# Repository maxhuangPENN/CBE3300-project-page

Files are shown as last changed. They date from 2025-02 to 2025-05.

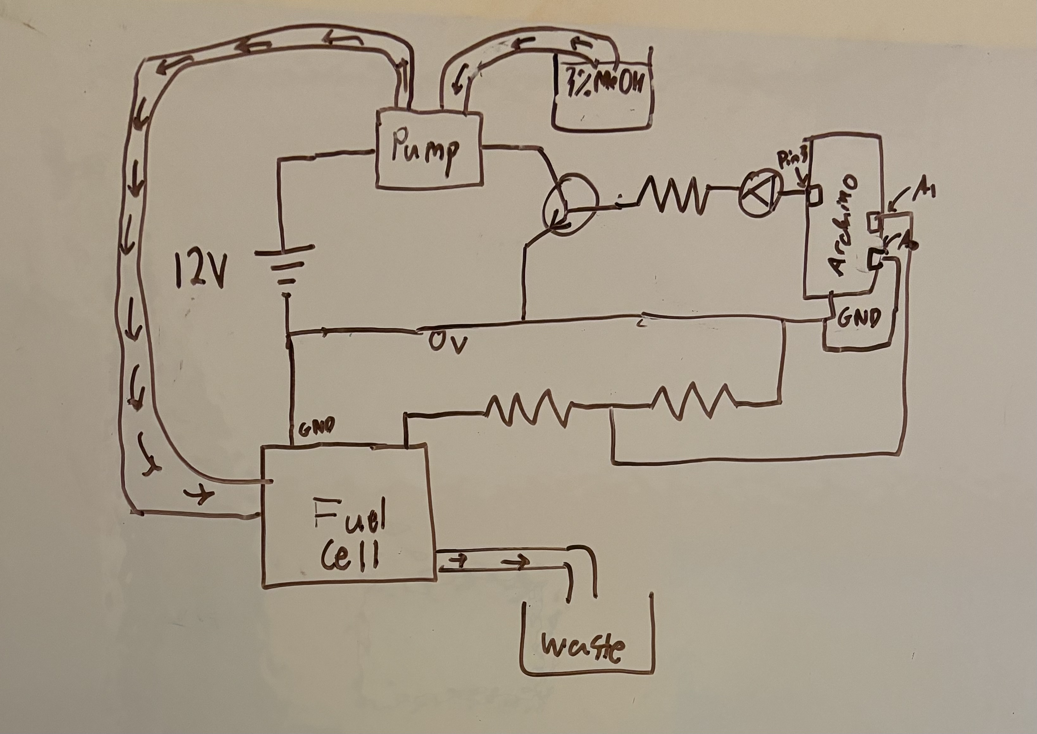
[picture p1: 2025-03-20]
IMG_6256.jpg

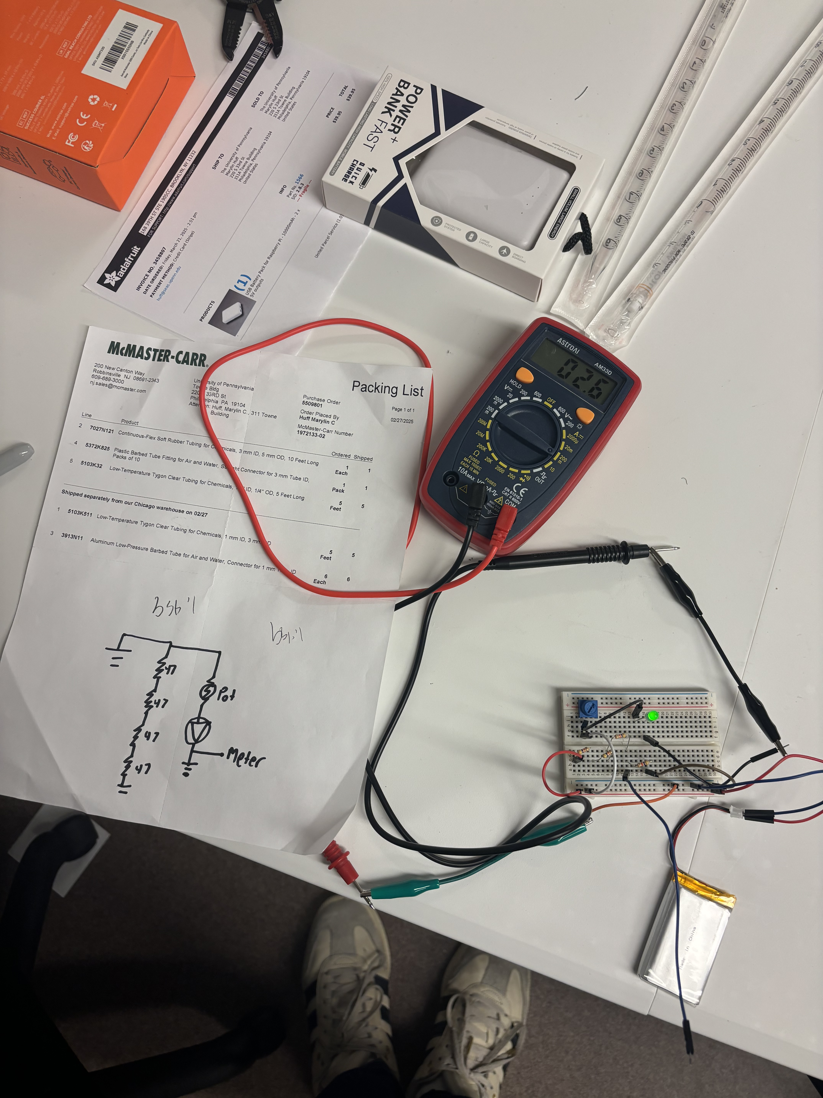
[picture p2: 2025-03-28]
IMG_6270.jpg

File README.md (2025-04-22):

---
title: "Project: Direct Methanol Fuel Cell (DMFC)"
toc: true
toc-depth: 2
numbersections: true
colorlinks: true
abstract-title: Summary
abstract: |
  This project explores the design and prototyping of a Direct Methanol Fuel Cell (DMFC) system using a 10-cell Flex-Stak from the Fuel Cell Store. 
  The cell operates on 3% methanol (~1M), and is designed to output sufficient voltage and current to charge a 20,000 mAh battery pack within 24 hours.
  
  Builders will gain experience with electrochemistry, fuel cell operation, real-time electronics integration with Arduino, and chemical process control. 
  Further extensions include MEA fabrication and advanced catalyst implementation.

  Approximate time: 20–30 person-hours.
---

# DMFC Project – Methanol Dynamics
University of Pennsylvania – CBE 3300B

---

## Project Description

This project explores the design and prototyping of a Direct Methanol Fuel Cell (DMFC) using a 10-cell Flex-Stak. It integrates passive and active fuel delivery, peristaltic pumping, and Arduino-based control logic to modulate methanol flow and monitor system voltage in real time.

Our goal is to develop a system that can charge a 20,000 mAh power bank in less than 24 hours while remaining safe, modular, and efficient. Future goals include fabricating our own MEA and testing alternate catalyst configurations.

---

## Background

DMFC stack and tubing setup

A DMFC converts chemical energy directly into electrical energy via redox reactions. Methanol is oxidized at the anode, producing CO₂, protons, and electrons. The electrons generate current through an external circuit, while protons migrate across a PEM to recombine with oxygen at the cathode, forming water.

**Anode reaction**:  
$$\ce{CH3OH + H2O -> CO2 + 6H+ + 6e-}$$

**Cathode reaction**:  
$$\ce{3/2 O2 + 6H+ + 6e- -> 3H2O}$$

**Overall reaction**:  
$$\ce{CH3OH + 3/2 O2 -> CO2 + 2H2O}$$

The theoretical cell voltage is ~1.20 V per cell, but practical values range between 0.3–0.6 V due to internal losses and crossover.

---

## Project Goals

- Develop a minimum viable DMFC prototype
- Integrate peristaltic pump control via PWM (Arduino)
- Monitor live voltage and adjust flow dynamically
- Run extended tests to estimate methanol consumption and power output
- Optimize stack layout and fuel delivery (horizontal vs vertical, vapor vs liquid)
- Charge a 20,000 mAh power bank in < 24 hours

---

## Equipment & Materials

### Hardware

- 10-cell Flex-Stak DMFC (Fuel Cell Store)
- Arduino Uno
- Diode-protected transistor circuit (2N2222 BJT)
- Peristaltic pump
- 3% methanol solution (~1M)
- Tubing, check valves
- USB data logging via Processing

### Software

- Arduino IDE for control logic and PWM duty modulation
- Processing for real-time plotting and CSV saving of voltage
- Python (optional) for data post-processing

---

## Build Instructions

1. **Assemble fuel cell stack** and torque bolts to 8–10 in-lbs
2. **Hydrate membrane** with distilled water before first use
3. Prepare **3% MeOH in water solution (~1M)** and prime pump lines
4. Upload [Arduino script](#arduino-code) and connect PWM to base of 2N2222 transistor
5. Open [Processing visualization](#processing-code) to log voltage and plot in real time
6. Begin testing and incrementally increase duty cycle or MeOH concentration if needed

---

## Arduino Code

```cpp
int pwmPin = 3; // Digital output pin connected to BJT base
int analogPin = A0; // Reads voltage (resistor divider used)

float dutyCycle = 1;      
float targetFlowrate = 100;
int pwmPeriodMs = 10;

boolean feedback = false;
float targetCellVoltage = 4;
int timer = 0;

void setup() {
  Serial.begin(9600);
  dutyCycle = targetFlowrate / 142.0;
  if (dutyCycle > 1.0) dutyCycle = 1.0;
  pinMode(pwmPin, OUTPUT);
  pinMode(analogPin, INPUT);
}

void loop() {
  int onTime = pwmPeriodMs * dutyCycle;
  int offTime = pwmPeriodMs - onTime;

  int sensorValue = analogRead(analogPin);
  float voltage = 4 * sensorValue * (5.0 / 1023.0);
  Serial.println(voltage);

  digitalWrite(pwmPin, HIGH);
  delay(onTime);
  digitalWrite(pwmPin, LOW);
  delay(offTime);

  if (feedback && timer % 1000 == 0) {
    if (voltage > targetCellVoltage + 0.1) dutyCycle -= 0.01;
    else if (voltage < targetCellVoltage - 0.1) dutyCycle += 0.01;
  }
  timer += pwmPeriodMs;
}

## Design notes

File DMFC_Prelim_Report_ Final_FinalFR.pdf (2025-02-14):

# Preliminary Design Report: Direct Methanol Fuel Cell

### Methanol Dynamics & Company LLP (Max, Jack, Karam)

### February 13, 2025

## Contents

1 Introduction | 2
2 Electrochemical Operation of a Direct Methanol Fuel Cell (DMFC) | 2
3 Prototyping Approach | 4
4 Project Timeline | 6
5 Preliminary Calculations | 8
6 Purchasing List | 10
7 References | 13

## 1 Introduction

This document presents the preliminary design report for our Direct Methanol Fuel Cell (DMFC) prototype. It includes an outline of the physical and chemical principles, relevant calculations, and a detailed prototyping approach.

## 2 Electrochemical Operation of a Direct Methanol Fuel Cell (DMFC)

The direct methanol fuel cell (DMFC) is an electrochemical device that converts the chemical energy of methanol into electrical energy through redox reactions. Unlike combustion, which releases energy primarily as heat, the DMFC harnesses this energy to drive electron flow, producing electricity in a controlled manner.

### 2.1 Anode Reaction: Methanol Oxidation

At the anode, methanol (CH3OH) and water (H2O) undergo oxidation in the presence of a catalyst, typically platinum (Pt) or platinum-ruthenium (Pt-Ru). This reaction results in the formation of carbon dioxide (CO2), protons (H⁺
), and electrons (e⁻):

CH3OH + H2O → CO2 + 6H⁺ + 6e

−

The oxidation pathway can vary, with some intermediates such as formaldehyde (CH2O) and formic acid (HCOOH). However, carbon monoxide (CO) can also form as a byproduct, which can poison the catalyst and reduce efficiency. The incorporation of ruthenium (Ru) helps mitigate this effect by facilitating CO oxidation.

### 2.2 Proton Exchange and Electron Flow

Adjacent to the anode is a proton exchange membrane (PEM), often made of Nafion, which plays a crucial role in directing charge flow. This membrane allows the passage of protons (H⁺
) from the anode to the cathode while preventing unwanted methanol crossover, a major source of efficiency loss in DMFCs. Meanwhile, the electrons generated at the anode travel through an external circuit, creating an electric current before reaching the cathode.

### 2.3 Cathode Reaction: Oxygen Reduction

At the cathode, oxygen gas (O2) is reduced in the presence of platinum or specialized catalysts such as RuSe, which help mitigate performance losses due to methanol crossover. The incoming oxygen reacts with protons from the membrane and electrons from the external circuit to form water:

3
2

O2 + 6H

+ + 6e

− → 3H2O

This reaction completes the circuit, sustaining continuous electron flow and thus electrical power generation.

### 2.4 Theoretical Maximum Voltage and Energy Efficiency

The ideal electromotive force (EMF) of a DMFC, derived from the Gibbs free energy change of the overall reaction:

3
2

O2 + CH3OH → CO2 + 2H2O

is approximately 1.2V per cell. However, due to losses from activation polarization, ohmic resistance, and mass transport limitations, practical operating voltages typically range between 0.3V and 0.6V per cell.
The overall efficiency of a DMFC is limited by factors such as methanol crossover, catalyst degradation, and water management. The Nernst equation can be used to account for real operating conditions and concentration variations:

E = E

0 −

RT
nF

ln Q

where: - E

0 = 1.20V (standard cell voltage), - R is the universal gas constant, - T is the operating temperature, - n = 6 (number of electrons transferred), - F is the Faraday constant, - Q represents the reaction quotient.

### 2.5 Summary of the DMFC Operation

- Anode: Methanol and water oxidize, producing protons, electrons, and carbon dioxide.
- Proton Exchange Membrane: Conducts protons to the cathode while preventing direct methanol crossover.
- Electron Flow: Electrons travel through an external circuit, generating electrical power.
- Cathode: Oxygen is reduced, combining with protons and electrons to form water.
- Voltage Output: The theoretical voltage is 1.2V, but actual efficiency and power output depend on operating conditions.

By optimizing reaction kinetics, catalyst selection, and fuel delivery methods, the performance of DMFCs can be significantly enhanced for real-world applications.

## 3 Prototyping Approach

Our prototyping approach follows a staged methodology aimed at optimizing the design and achieving the highest possible voltage for our direct methanol fuel cell (DMFC).

### 3.1 Minimum Viable Prototype (MVP)

Our first goal is to construct a functional minimum viable prototype (MVP) using a liquid methanol feed with passive control. This design choice ensures simplicity and feasibility in the early stages while providing a solid baseline for future modifications.

- Membrane Electrode Assembly (MEA): Instead of fabricating our own initially, we will purchase a commercial MEA, ensuring reliability and allowing us to quickly test basic system functionality.
- Passive Fuel Delivery: Passive DMFCs operate without auxiliary equipment such as pumps or sensors, relying on diffusion and natural convection to transport reactants (methanol and oxygen). This simplifies the initial build and reduces complexity.
- Basic Performance Metrics: We will measure voltage and current output to assess the baseline performance before proceeding with optimizations.

### 3.2 Optimization and Enhancements

Once the MVP is operational, we will explore modifications to improve performance, focusing on increasing voltage output. Our planned optimizations include:

### 3.2.1 Active Control Implementation

- Introducing sensors (e.g., flow meters, temperature sensors, and concentration monitors) to monitor and control reactant flow dynamically.
- Using Arduino-based control systems to regulate fuel flow rate and oxygen supply.
- Implementing an external fuel delivery system, such as a micropump, for better methanol concentration control.

### 3.2.2 Vapor vs. Liquid Feed Comparison

- Testing vaporized methanol feed instead of a direct liquid feed. Vapor feed reduces methanol crossover, increases reaction rates, and can improve fuel cell efficiency.
- Assessing temperature effects on reaction kinetics, as vapor feed operates at higher temperatures, potentially improving performance.

### 3.2.3 Geometrical Configurations

- Evaluating horizontal vs. vertical orientations for the fuel cell stack to optimize carbon dioxide removal and fuel distribution.
- Investigating different anode diffusion layers (ADL) and cathode diffusion layers (CDL) to improve fuel transport and reaction efficiency.

### 3.2.4 MEA Fabrication

- Concurrently, we will attempt to build our own MEA from individual components, including a proton exchange membrane (PEM) and Pt-Ru catalyst layers.
- If the self-assembled MEA does not meet performance expectations, we will continue to rely on the purchased MEA while refining our fabrication techniques.

### 3.2.5 Final Voltage Benchmark and System Refinement

- Our target voltage is 5V, requiring serial or parallel stacking of multiple fuel cells.
- We will fine-tune parameters such as methanol concentration, flow rates, and operating temperature to maximize efficiency.

### 3.3 Future Considerations

Once the fundamental optimizations are completed, we will explore further advanced techniques, such as:

- Alternative catalysts to reduce reliance on platinum.
- 3D printing of structural components to streamline manufacturing.
- Hybrid fuel systems, integrating hydrogen or other fuels for improved energy density.

This structured prototyping approach ensures a logical progression from a functional baseline to an optimized DMFC capable of achieving high voltage and efficiency.

## 4 Project Timeline

The following timeline outlines the key milestones and deliverables for our Direct Methanol Fuel Cell (DMFC) development. Our final presentation is scheduled for Week 14, and we will use the time leading up to it to iteratively refine our design, optimize performance, and validate results.

### 4.1 Development Plan

- Week 2 (Completed): Literature review, background research on DMFC operation, and identification of required materials.
- Week 4 (Current Week):

– Karam emails Dr. Huff to confirm parts order.

– Initiate 3D printing of preliminary components.

– Complete and submit preliminary design report by Friday, February 7.

- Week 5:

– Finalize component orders and track deliveries.

– Begin assembling the initial prototype with purchased MEA.

– Conduct preliminary voltage tests to establish baseline performance.

- Weeks 6-7:

– Integrate sensors and begin active control implementation.

– Evaluate liquid feed performance and compare to theoretical predictions.

– Troubleshoot any early-stage performance issues.

- Week 8:

– Assess horizontal vs. vertical fuel cell orientation for optimal CO2 removal.

– Test impact of varying methanol concentrations on performance.

– Refine 3D-printed components if necessary.

- Weeks 9-10:

– Investigate vapor feed vs. liquid feed system performance.

– Implement Arduino-based active control for flow rate optimization.

– Verify sensor accuracy and calibrate data collection systems.

- Week 11:

– Attempt self-assembly of MEA using PEM and catalyst layers.

– Compare performance of self-made MEA against the commercial MEA.

– Identify any efficiency losses and determine feasibility of custom MEA.

- Weeks 12-13:

– Conduct final optimization rounds to maximize voltage output.

– Implement fine-tuned methanol and oxygen flow controls.

– Finalize system architecture to reach 5V target.

- Week 14 (Final Presentation Week):

– Deliver final presentation showcasing experimental results, optimizations, and key takeaways.

– Submit final report with performance benchmarks and analysis.

## 5 Preliminary Calculations

Accurate theoretical calculations are essential for predicting the performance of our direct methanol fuel cell (DMFC) and optimizing its efficiency.

### 5.1 Nernst Equation Calculations

The voltage output of a DMFC can be estimated using the Nernst equation, which accounts for concentration effects:

E = E0 −

RT
nF

ln Q

where:

- E0 = 1.20 V (Standard electromotive force for DMFC) [1]
- R = 8.314 J/(mol·K) (Universal gas constant)
- T = 298 K (Assumed room temperature)
- n = 6 (Number of electrons transferred per reaction)
- F = 96, 485 C/mol (Faraday’s constant)
- Q is the reaction quotient, given by:

Q =

[CO2][H2O]²
[CH3OH][O2]

3/2

Input Parameters:

- Methanol concentration: Typically ranges from **0.1 M to 1.0 M** in DMFCs.
- Oxygen partial pressure: **0.21 atm** (assuming air as the oxidant).
- Carbon dioxide concentration: Starts near **0 atm**, depending on reaction rate.
- Estimated reaction quotient: Q ≈ 1 − 10, depending on real conditions.

### 5.2 Theoretical Maximum Voltage

The standard theoretical maximum voltage of a DMFC is:

E0 = 1.20 V

This value represents the ideal potential assuming no losses in the system.

### 5.3 Estimated Efficiency and Target Voltage

Fuel cell efficiency can be estimated from experimental data:

- Assumed efficiency: **40
- Expected operational voltage range: **0.3V - 0.6V per cell**.
- Target voltage for system design: **4V - 6V** by stacking multiple cells.

The system voltage goal of **5V** will be achieved through a combination of optimized methanol feed, temperature control, and serial/parallel stacking.

## 6 Purchasing List

The following is a comprehensive list of components required for constructing and optimizing our direct methanol fuel cell (DMFC) prototype. This includes essential materials, sensors for active control, vapor feed components, and equipment for building our own MEA.

** Clicking on the reference number leads to the References, where we documented all links to purchasing websites.

### 6.1 Core Fuel Cell Components

- Membrane Electrode Assembly (MEA)

– Membrane Thickness: 170 micrometers
– Anode Catalyst: Platinum-Ruthenium (4.0 mg/cm² )
– Cathode Catalyst: Platinum Black (4.0 mg/cm²
)
– Gas Diffusion Layer: Carbon Cloth with Microporous Layer (MPL) – Cost: Starting from $170.00 (2.2 cm x 2.2 cm option) [3]
- Current Collectors

– Material: Gold-plated stainless steel or similar conductive materials – Purpose: Facilitates electron collection and improves electrical contact – Cost: Approximately $30 each [4]

- Proton Exchange Membrane (PEM)

– Material: Nafion (included in MEA)

– Purpose: Allows proton conduction while blocking electrons – Key Consideration: Minimizing methanol crossover

### 6.2 Active Control and Monitoring Components

- Sensors and Meters

– Flow Meters – For measuring methanol and oxygen flow rates
– Temperature Sensors – To monitor heat buildup and optimize reaction conditions
– Concentration Monitors – To ensure proper methanol-to-water ratio
– Voltage and Current Sensors – For real-time electrical performance monitoring
- Control Systems

– Arduino-based Microcontroller – For automated fuel and oxygen flow regulation
– Actuators and Pumps – To enable precise control of methanol feed
– Power Management Module – To integrate the fuel cell with external loads

### 6.3 Vapor Feed System

- Methanol Vaporizer – Converts liquid methanol into gas phase for testing vapor feed performance
- Gas Flow Regulators – To control methanol vapor concentration and delivery rate
- Humidifier Chamber – Ensures proper humidification for proton exchange membrane operation

### 6.4 MEA Fabrication Equipment

- Catalyst Ink Materials – Platinum-ruthenium nanoparticles, solvents, and binders
- Screen Printing Equipment – For catalyst layer deposition on gas diffusion electrodes
- Hot Press – For assembling homemade MEA layers under controlled pressure and temperature
- Electrochemical Workstation – For characterizing custom MEA performance

### 6.5 3D-Printed and Custom Components

- Custom Flow Field Plates – Designed to optimize reactant distribution
- Housing and Fixtures – For secure and leak-proof fuel cell assembly
- Tubing and Connectors – To manage liquid and vapor fuel delivery

This purchasing list ensures that we have all necessary components for our staged prototyping approach, from initial passive control to advanced active regulation and MEA fabrication.

Important to keep in mind:

Items listed that pertain to optimizing our fuel cell beyond the MVP do not have purchasing costs or links associated with them. This is because, once we achieve the MVP, significant testing and experimentation will be required before committing to specific sensors and the type of feed system we want to pursue. For instance, it would be impractical to purchase a vaporizer if we ultimately decide that a liquid feed system is more efficient for our setup.

Additionally, given methanol’s Safety Data Sheet (SDS) considerations, we must carefully evaluate the best methods for delivering vaporized methanol. Our current best approach (recommended by Dr. Huff) involves bubbling nitrogen through methanol to pick up vapor and transport it into the system, but this method is still under evaluation.

Furthermore, we anticipate that many of the basic sensors and equipment required for testing can be sourced from Towne, either through direct access to shared lab resources or by consulting Dr. Huff. While we recognize that borrowing equipment from research labs is not ideal, we believe that simple components like flow meters and temperature sensors should be readily available for our early testing phases.

Finally, once our testing is complete and we finalize our fuel cell’s optimization needs, we do not expect a significant lead time for ordering the required products and sensors, allowing us to proceed efficiently without unnecessary upfront purchases.

## 7 References

## References

[1] Direct Methanol Fuel Cells – Nernst Equation and Performance Analy-
sis. | Available | at: | https://www.sciencedirect.com/topics/chemistry/
direct-methanol-fuel-cell (https://www.sciencedirect.com/topics/chemistry/direct-methanol-fuel-cell)
[2] DMFC Efficiency Study: “The potential efficiency (εf ) of a DMFC for an operational cell e.m.f. (E) of 0.5 V is about 40%.” Available at: https://www.sciencedirect.com/topics/chemistry/direct-methanol-fuel-cell (https://www.sciencedirect.com/topics/chemistry/direct-methanol-fuel-cell)
[3] Fuel Cell Store – Direct Methanol MEA. Available at: https://www.fuelcellstore.com/direct-methanol-mea (https://www.fuelcellstore.com/direct-methanol-mea)
[4] MSE Supplies – Gold-Plated Current Collectors. Available at: https://www.msesupplies.com/products/pt-and-au-wire-0-6-mm-dia-10-mm-length-unit
[5] Methanol-Resistant Oxygen-Reduction Catalysts for Direct Methanol Fuel Cells. Available at: https://www.annualreviews.org/content/journals/10.1146/annurev.matsci.33.072302.093511 (https://www.annualreviews.org/content/journals/10.1146/annurev.matsci.33.072302.093511)
[6] Limiting Current Behavior of the Direct Methanol Fuel Cell. Available at: https: //www.sciencedirect.com/science/article/pii/S0013468699002856
[7] Performance of a Direct Methanol Fuel Cell. Available at: https://link.springer.com/article/10.1023/A:1003263632683 (https://link.springer.com/article/10.1023/A:1003263632683)
[8] Chapter 14: Direct Methanol Fuel Cells, Methanol: Science and Engineering, Angelo Basile, Francesca Dalena (Eds.), Elsevier, 2018. Available at: https://www.amazon.com/Methanol-Science-Engineering-Angelo-Basile/dp/0444639039 (https://www.amazon.com/Methanol-Science-Engineering-Angelo-Basile/dp/0444639039)

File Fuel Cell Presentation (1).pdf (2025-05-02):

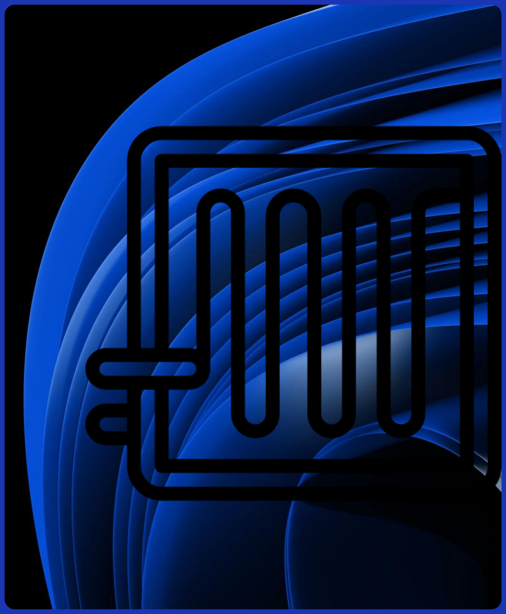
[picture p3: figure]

Confidential | Copyright ©

# Fuel Cell

## Jack, Karam, Max

5/7/25

Methanol
Dynamics

# Fuel Cell Market

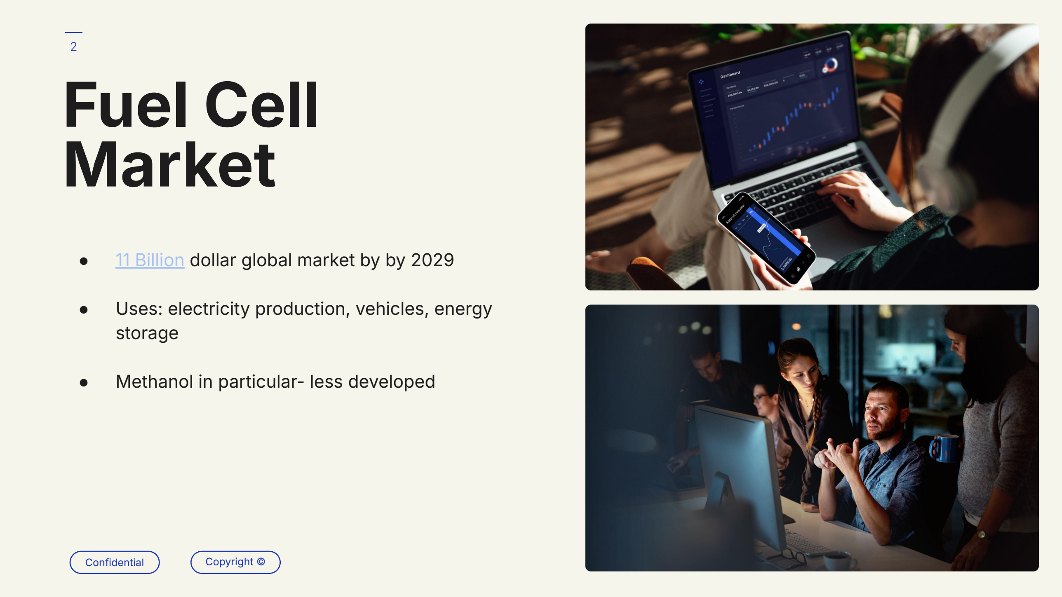
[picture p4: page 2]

- 11 Billion (https://www.bccresearch.com/market-research/energy-and-resources/hydrogen-fuel-cell-market.html) dollar global market by by 2029
- Uses: electricity production, vehicles, energy storage
- Methanol in particular- less developed

# SWOT Analysis

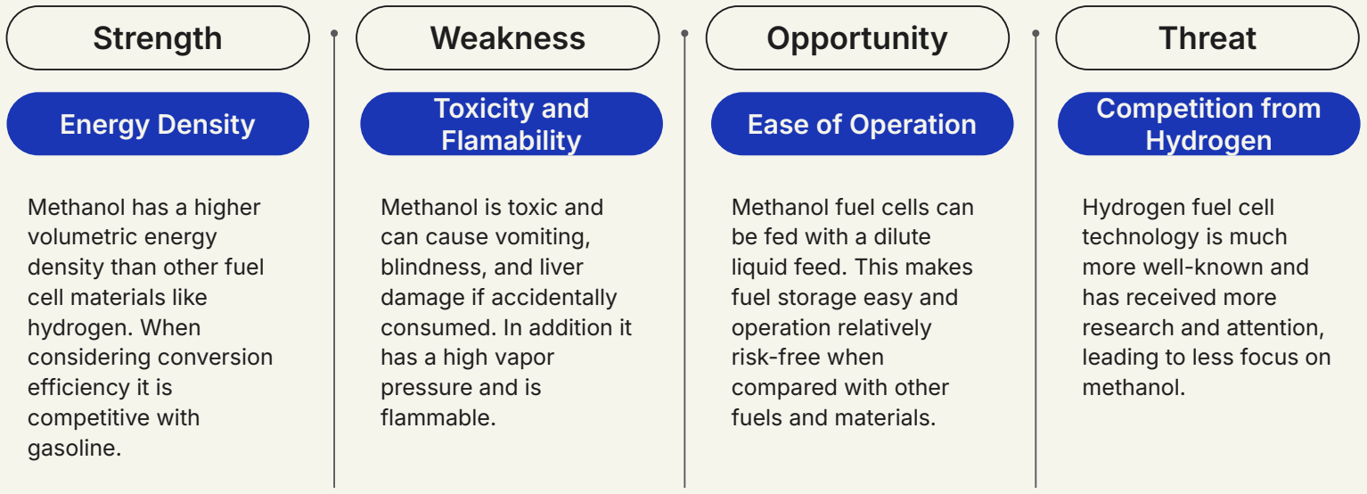
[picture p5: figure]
Methanol has a higher volumetric energy density than other fuel cell materials like hydrogen. When considering conversion efficiency it is competitive with gasoline.; Methanol is toxic and can cause vomiting, blindness, and liver damage if accidentally consumed. In addition it has a high vapor pressure and is flammable.; Methanol fuel cells can be fed with a dilute liquid feed. This makes fuel storage easy and operation relatively risk-free when compared with other fuels and materials.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

# Competitor Analysis

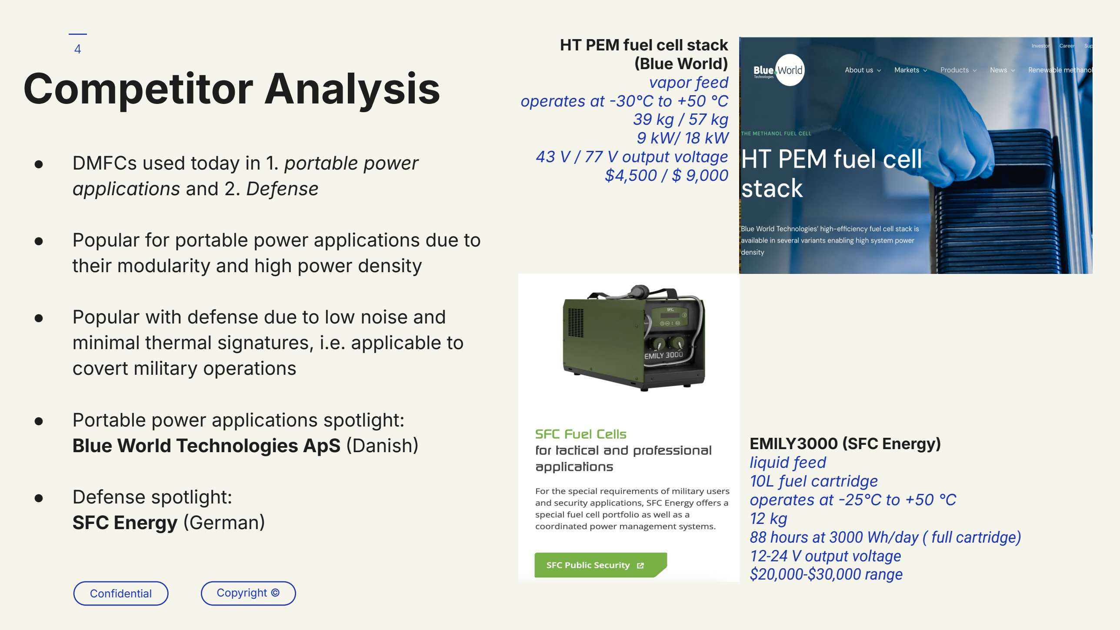
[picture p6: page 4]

- DMFCs used today in 1. portable power applications and 2. Defense
- Popular for portable power applications due to their modularity and high power density
- Popular with defense due to low noise and minimal thermal signatures, i.e. applicable to covert military operations
- Portable power applications spotlight:
Blue World Technologies ApS Danish
- Defense spotlight:
SFC Energy German

EMILY3000 SFC Energy)
liquid feed
10L fuel cartridge
operates at 25°C to 50 °C
12 kg
88 hours at 3000 Wh/day ( full cartridge) 12-24 V output voltage
$20,000-$30,000 range

HT PEM fuel cell stack
Blue World)
vapor feed
operates at 30°C to 50 °C 39 kg / 57 kg
9 kW/ 18 kW
43 V / 77 V output voltage $4,500 / $ 9,000

- Target Recreational & Off-Grid Consumers – Target campers, RV users, and outdoor enthusiasts seeking reliable, clean portable power
- Target Military & Defense – Focus on tactical applications requiring low-noise, low-thermal signature power for covert operations
- Geographic Focus – Developed Markets – Prioritize North America, where competitors dominate the European market
- Geographic Focus – Emerging Markets – Expand into Southeast Asia and Latin America, where grid instability drives demand for off-grid solutions
- Leverage Green Energy Incentives – Capitalize on tax benefits and government/corporate subsidies, though opportunities in North America may be limited Trump administration)
- Strategic Partnerships in Renewable Energy – Collaborate with battery and renewable energy companies to develop hybrid systems

# Marketing Strategy and Opportunity

# Progress & Timeline

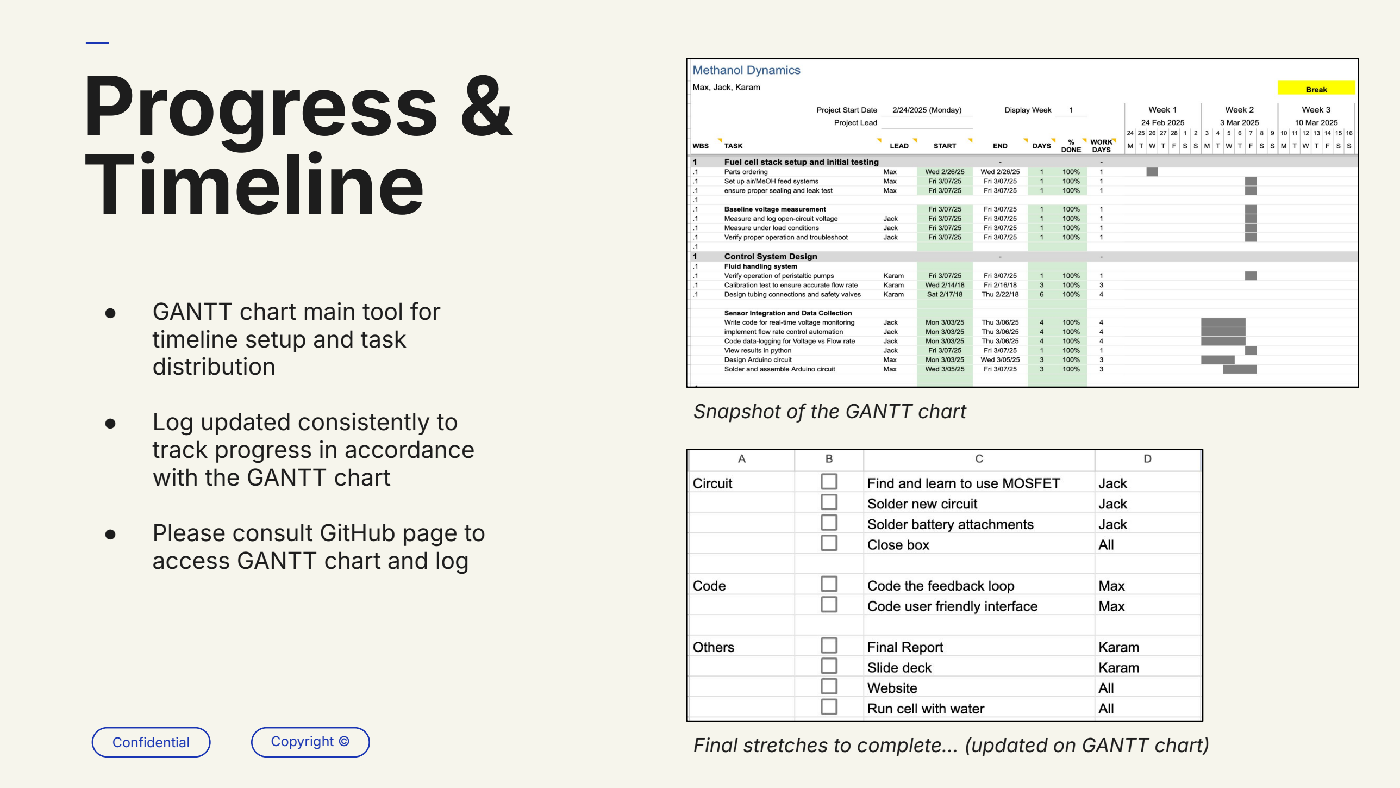
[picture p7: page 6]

- GANTT chart main tool for timeline setup and task
distribution
- Log updated consistently to track progress in accordance with the GANTT chart
- Please consult GitHub page to access GANTT chart and log

Snapshot of the GANTT chart

Final stretches to complete… (updated on GANTT chart)

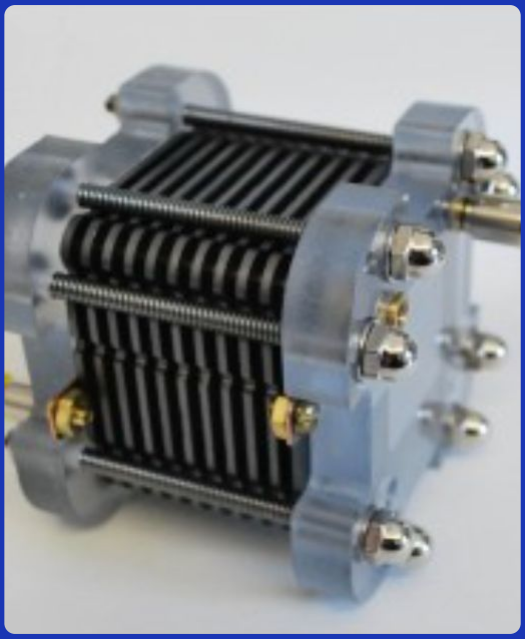
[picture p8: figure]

# Fuel Cell Design

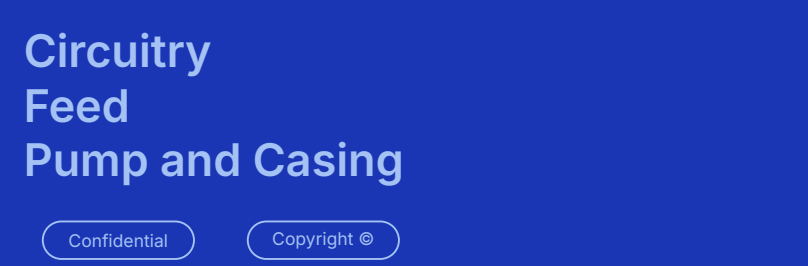
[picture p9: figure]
Circuitry Feed Pump and Casing

# Initial Design Plan

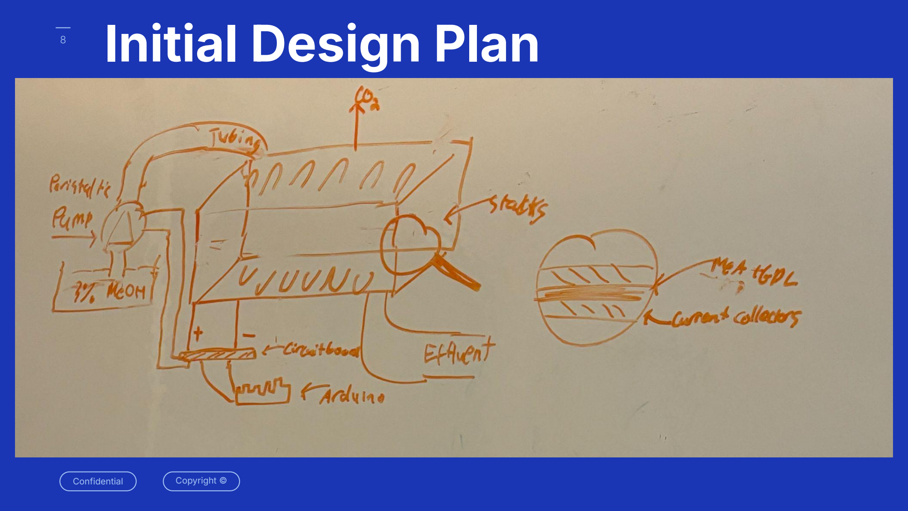
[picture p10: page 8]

# 9 Final Design Plan: Information Flow

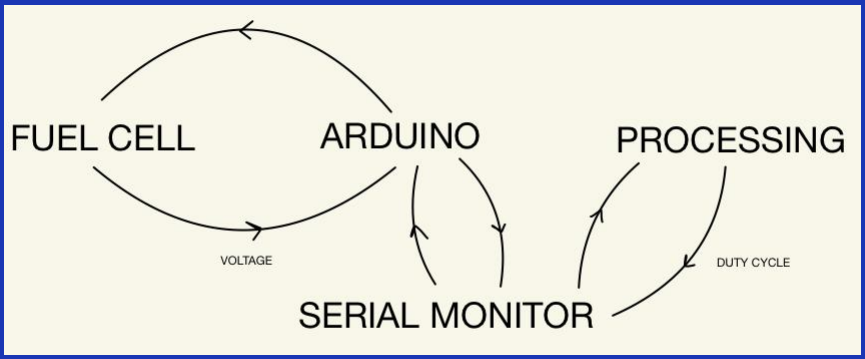
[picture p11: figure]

# 10 Final Design Plan: Circuitry

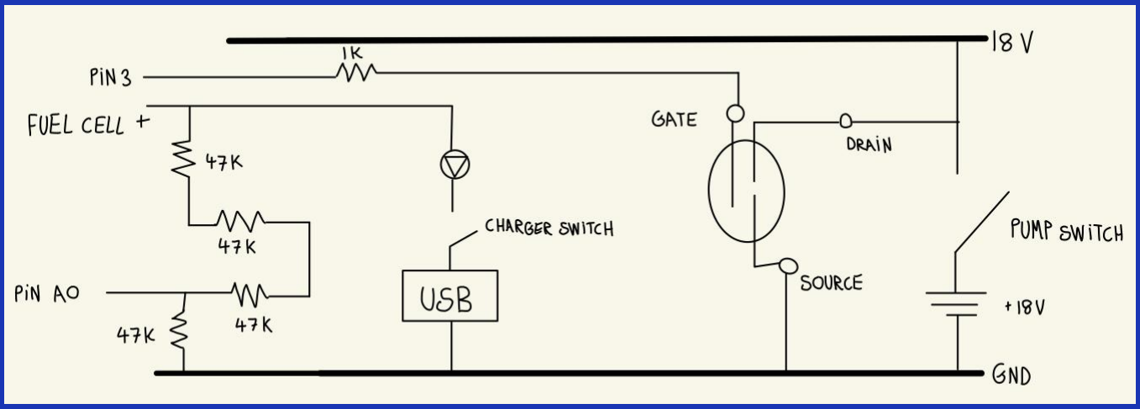
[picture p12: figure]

# 11 Final Design Plan: Architecture

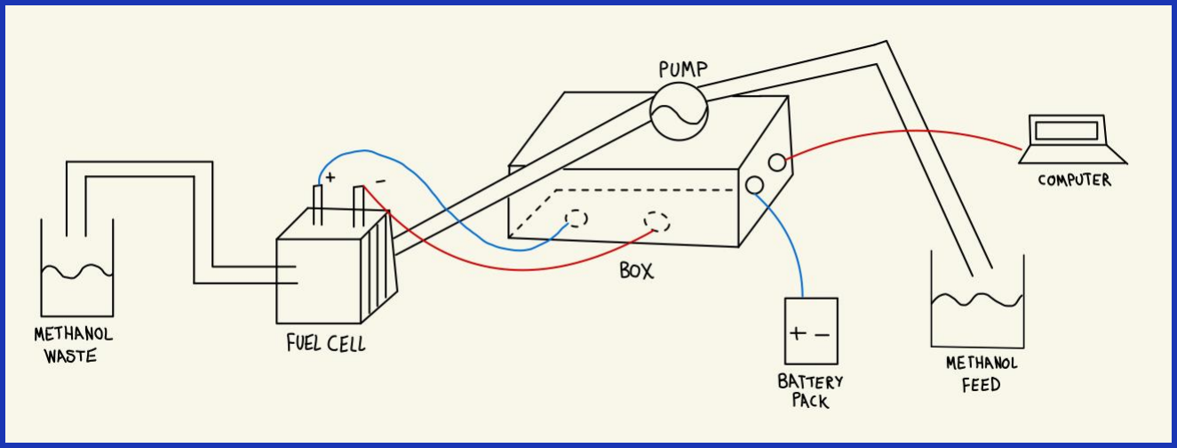
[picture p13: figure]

# 12 Circuitry: Architecture

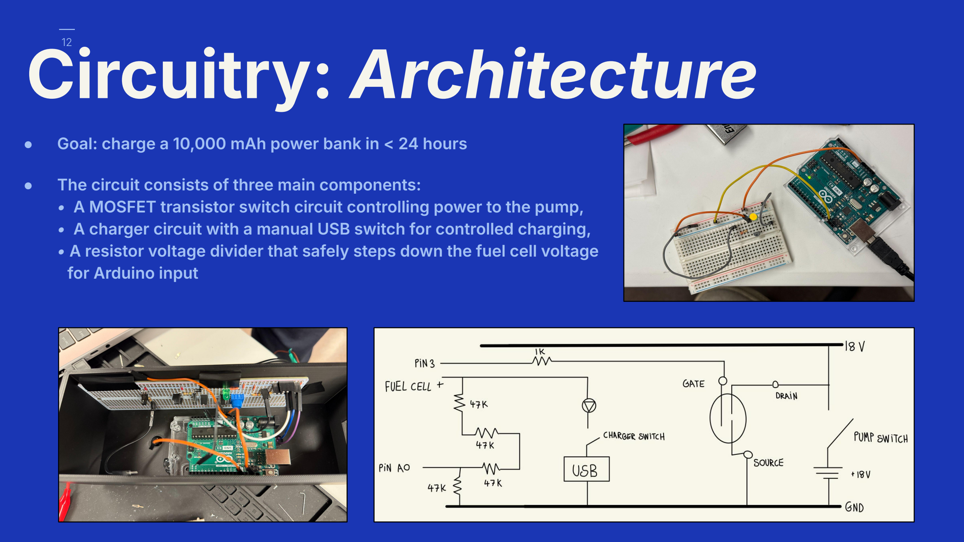
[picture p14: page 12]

- Goal: charge a 10,000 mAh power bank in < 24 hours
- The circuit consists of three main components:
- A MOSFET transistor switch circuit controlling power to the pump,
- A charger circuit with a manual USB switch for controlled charging,
- A resistor voltage divider that safely steps down the fuel cell voltage ..for Arduino input

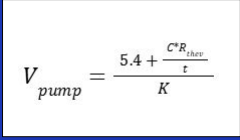
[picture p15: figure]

# Code: Calculation

- K is the ratio of open cell voltage to pump voltage;
- Unitless constant derived empirically from experimental data
..at various pump voltages,
- Assumed to remain constant across runs
- C is the chargerʼs capacity (in amp-hours), specified on the charging pack
- t is the desired charge time in hours (user input)
- Rₜₕₑᵥ is the Thevenin equivalent resistance of the fuel cell, determined from prior loading experiments
- The power pack charges at a constant voltage of 5.4 V. If the fuel cell's open-circuit voltage exceeds 5.4 V, the difference drives a current into the charging pack of I = ΔV / R
- Pump voltage, duty cycle, and flow rate are all directly proportional
- User inputs charge time; code delivers duty cycle

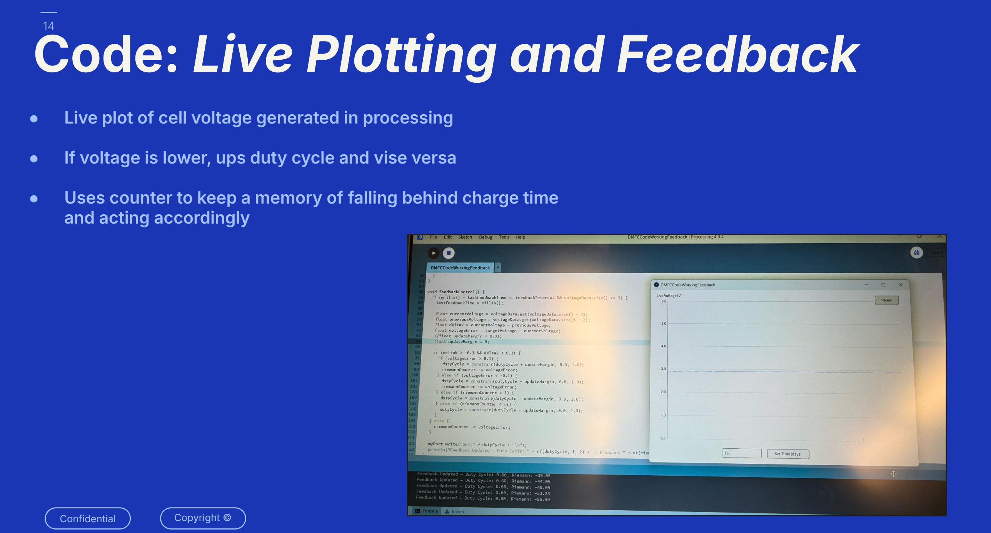
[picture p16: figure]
Code: Live Plotting and Feedback; and acting accordingly

- Live plot of cell voltage generated in processing
- If voltage is lower, ups duty cycle and vise versa
- Uses counter to keep a memory of falling behind charge time

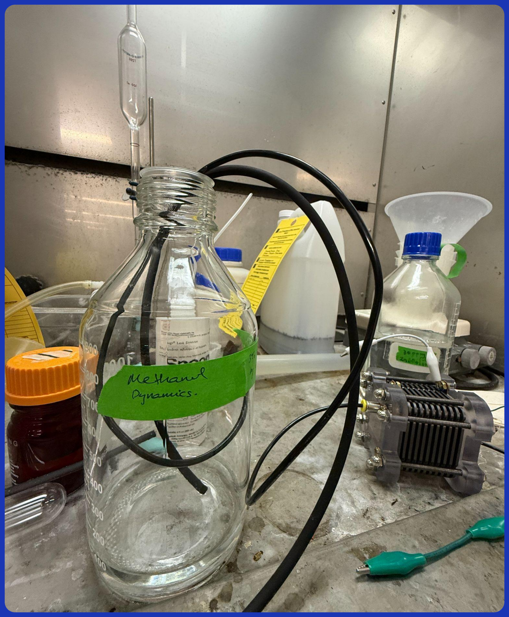
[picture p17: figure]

# Feed

### - 3% methanol 1M) feed - Room temperature

- Possible byproducts include CO, CO₂,

### hydroxymethyl-group compounds - Airflow may limit performance; fan supplies air to fuel cell - 4.32 L methanol required; 10 L stocked 3 mL/min * 1440 min/day = 4.32 L - Assume 24h feed

# Pump and Casing

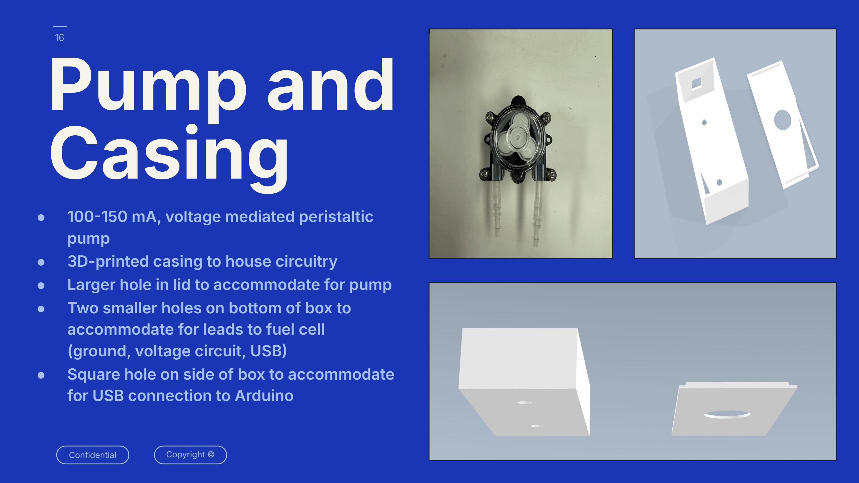
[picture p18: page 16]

- 100150 mA, voltage mediated peristaltic pump
- 3D-printed casing to house circuitry
- Larger hole in lid to accommodate for pump
- Two smaller holes on bottom of box to accommodate for leads to fuel cell (ground, voltage circuit, USB
- Square hole on side of box to accommodate for USB connection to Arduino

# ChemE Principles

- Applied mass and energy balances to design fuel and air feed systems
- Applied chemical process safety principles, particularly in handling methanol
- Gained hands-on skills in soldering and Arduino script programming
- Utilized electrochemical principles to predict fuel cell performance, including Nernst equation
- Chemical process control through feedback loop

- Unable to confirm if air was a limiting factor due to lack of control over airflow
- Lower-than-expected voltage efficiency 33%, limiting effective power delivery
- Occasional transistor failures from voltage or thermal issues
- Low current delivery; implying low conversion of methanol
- Cleansing fuel cell led to improved operation but still not very efficient
- Replacing BJT with MOSFET led to more reliable circuit
- Running the fuel cell at elevated temperatures
- Experimenting with different methanol concentrations

# Setbacks, growth, and next steps

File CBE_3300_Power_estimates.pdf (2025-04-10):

# CBE 3300B Power Estimates

Max Chen Huang

February 2025

## Power Estimations and Fuel Calculations

System Parameters

- Fuel Cell Stack: 10 cells in series
- Active Area per Cell: 10 cm²
- Estimated Current Density: 50–100 mA/cm²
- Total Current Output: 5 A (at 50 mA/cm²
)
- Expected Voltage Output: 3.8 V under load, 4.3 V open circuit
- Expected Power Output: 19 W at 50 mA/cm²
, up to 32 W at 100
mA/cm²

Methanol Consumption Estimate

- Feed Concentration: 3% methanol by mass (approx. 1M)
- Feed Rate: 100 cc/min = 6 L/hr
- Specific Gravity of Methanol: 0.792 g/mL
- Estimated Methanol Content: ∼143 g/hr
- Energy Density of Methanol: 6 kWh/kg
- Effective Power (20% conversion efficiency):

P = 143 g/hr ×

6 kW h
1000 g

× 0.20 = 0.17 kW h/hr = 170 W

1

Discrepancy in Theoretical vs Experimental Power

- Power estimated from current density and area: 19–32 W
- Power estimated from fuel energy content and conversion efficiency: 170 W
- Conclusion: Discrepancy of nearly one order of magnitude suggests potential overestimation of methanol conversion efficiency or underestimation of actual current output. Further experimental validation is needed.

Charge Time Estimation

- Battery Target: 20,000 mAh at 4 V = 80 Wh
- Assuming Ideal Output:

t =

80 W h
19 W

≈ 4.2 hours

- Optimistic Scenario: 3 hours (with higher current or power output)
- Conservative Target: Charging within 24 hours would still represent a successful benchmark

Crossover and Efficiency Considerations

- Pure methanol leads to higher crossover, resulting in cathode poisoning and wasted fuel.
- Voltage decay due to crossover can reduce performance by up to 30% within the first few hours.
- Decision: Start with 1M methanol feed and incrementally increase concentration while monitoring crossover and power output. Crossover is especially significant for longer operating times.

2

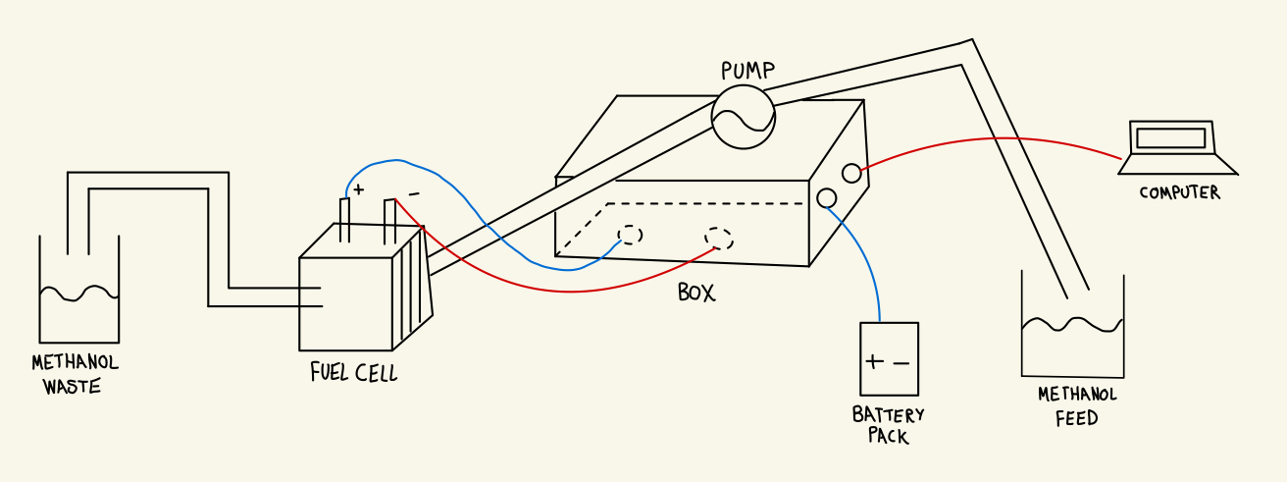
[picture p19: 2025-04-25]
fuelcellarchitecture.jpg

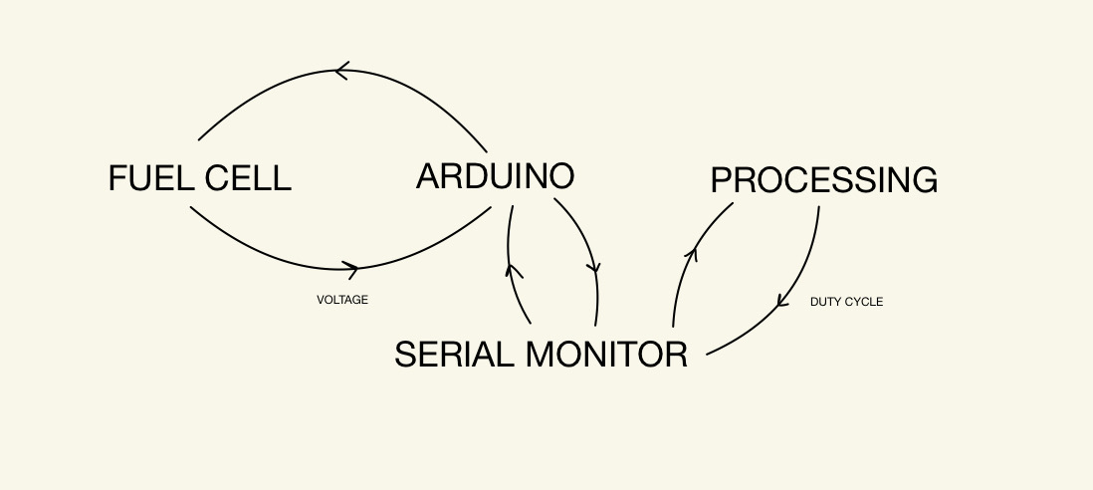
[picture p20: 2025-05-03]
imageimage.jpg

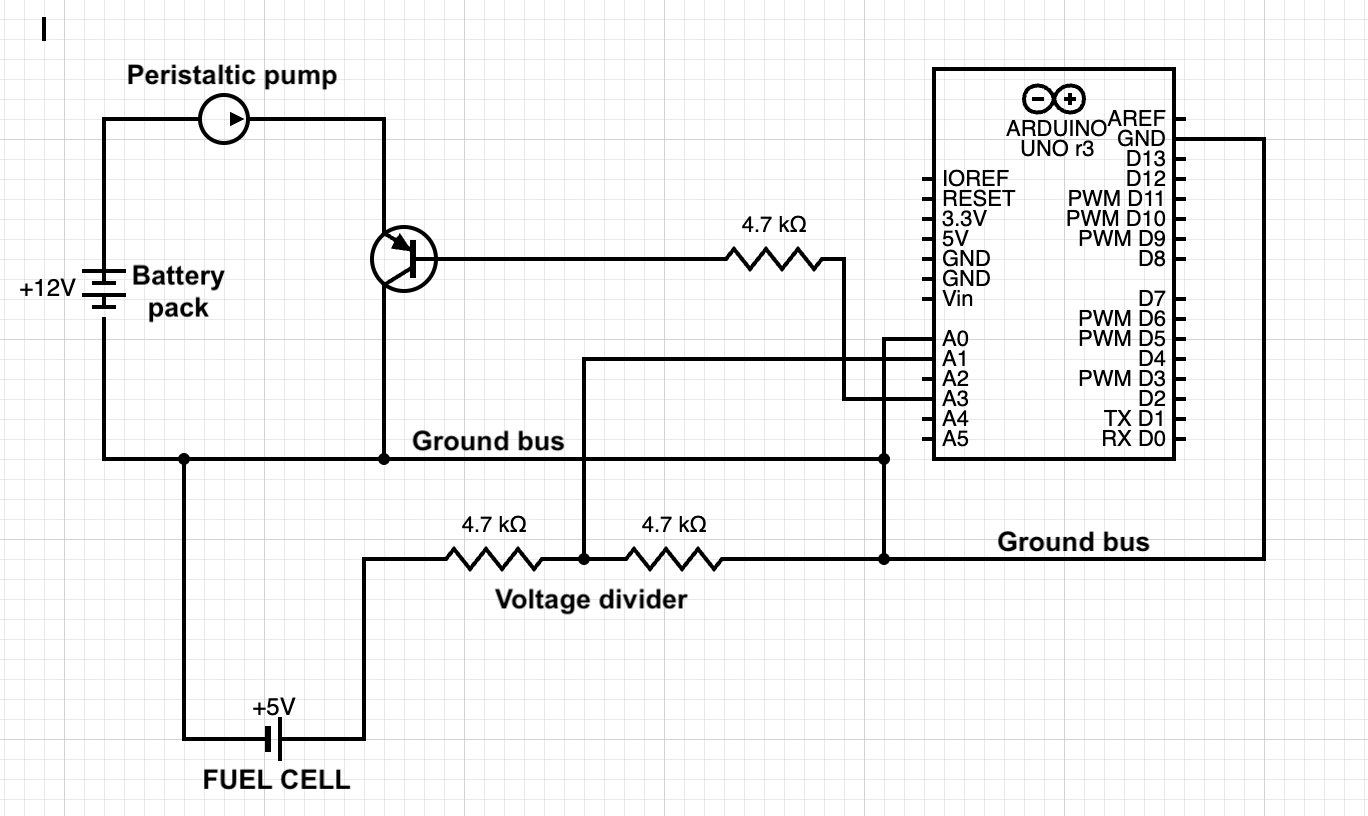
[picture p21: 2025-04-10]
DMFC-circuit-cad-2.png

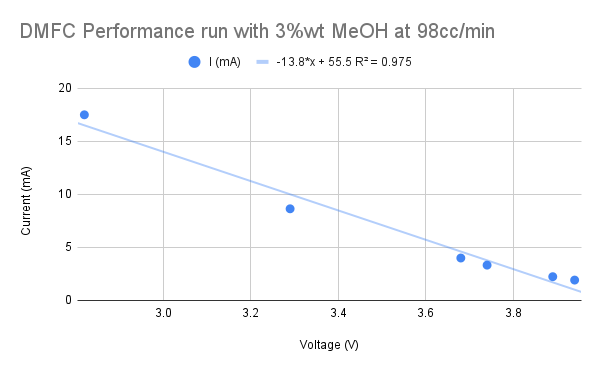
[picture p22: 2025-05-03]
IV-plots.png

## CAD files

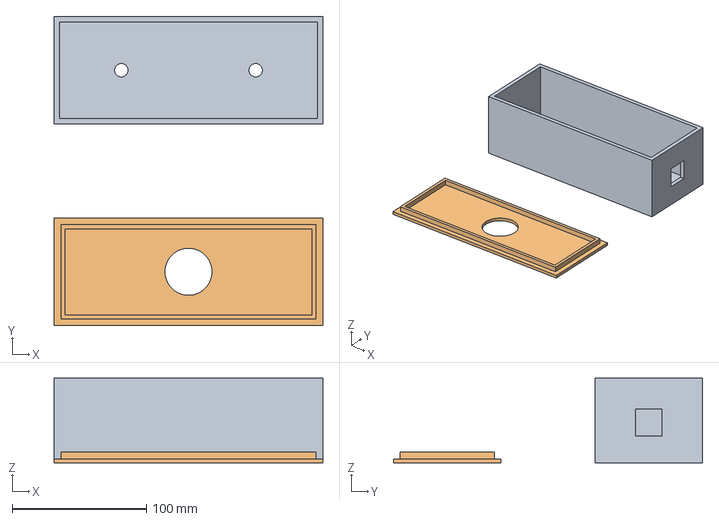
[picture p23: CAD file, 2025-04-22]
FuelCellCircuitHousing v1.3mf
200.0 x 230.0 x 63.0 mm

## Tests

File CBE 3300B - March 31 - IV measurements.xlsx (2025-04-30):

Running the cell (varying the pot between measurements)
V (V) | I (mA) | P (mW)
 |  |  | Power output is higher at higher higher current runs
3.94 | 1.92 | 7.5648
3.89 | 2.24 | 8.7136
3.74 | 3.33 | 12.4542
3.68 | 4 | 14.72
3.29 | 8.64 | 28.4256
2.82 | 17.5 | 49.35
4.5 (unloaded) | flow rate = 98 cc/min
Measurements after cutting MeOH supply (no pot changes, data collected over 5 mins)
4.06 | 3.28 | 13.3168
3.94 | 3.23 | 12.7262
3.91 | 3.19 | 12.4729
3.9 | 3.22 | 12.558

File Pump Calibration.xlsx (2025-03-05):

Voltage | Volume (mL) | Flowrate in mL/s
7 | 75 | 1.25
8 | 89 | 1.483333333 | Enter Volume | 100
9 | 106.5 | 1.775 | Voltage: | 8.618181818
10 | 124 | 2.066666667
11 | 142 | 2.366666667
12 | 151 | 2.516666667
14 | 192 | 3.2

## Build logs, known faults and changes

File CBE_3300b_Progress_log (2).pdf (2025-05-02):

# Methanol Dynamics & Co. LLP

## Direct Methanol Fuel Cell (DMFC) Project

### CBE 3300B, University of Pennsylvania Spring 2025

## Progress Log

- January 30: We evaluated liquid versus vapor methanol feed modes.

– Reviewed trade-offs of methanol crossover versus reaction kinetics.

– Selected a Pt–Ru catalyst to minimize CO poisoning, based on recent literature.

– Outlined MVP prototype: active feed with peristaltic pump, Arduino and Processing for controls, 10-cell stack from the Fuel Cell Store.

- January 31: We drafted the Preliminary Report framework in Dr. Huff’s lab.

– Assigned report sections (electrochemistry, prototyping, safety).

– Peer-reviewed our work.

– Defined milestones for finalizing the report by February 4.

- February 4: We completed the first full draft of the Preliminary Report.

– Identified optimal methanol concentration (3 wt%) for initial tests.

– Performed back-of-envelope power and fuel consumption calculations.

– Established experimental design matrix: feed mode, stack orientation, temperature.

- February 13: We presented the draft to our class and uploaded materials to GitHub.

– Collected feedback on scope and clarity.

– Finalized purchasing list for MVP, tubing, sensors, and pump.

– Scheduled MVP testing with Dr. Huff for the following week.

- February 14: We incorporated review comments and submitted the revised report.
- February 21: We disassembled a PEM electrolyzer to examine internal components.

– Studied membrane-electrode assembly structure and catalyst ink distribution.

– Researched methanol vaporization techniques to reduce crossover.

- February 24–25: We ordered the 10-cell Flex-Stak DMFC and supporting hardware.

– Finalized Gantt chart in Google Sheets, outlining fourteen-week timeline.

– Procured peristaltic pump, Nafion tubing, flow meters, and temperature sensors.

- March 2–3: We designed and breadboarded the Arduino-based control circuitry.

– Developed PWM code for pump speed regulation.

– Created a calibration protocol: measured pump flow vs. voltage.

– Logged preliminary Q–V data in Jupyter notebooks for analysis.

- March 4–5: We performed full pump calibration and tubing swelling tests.

– Characterized flow rates from 9 V to 18 V, plotted calibration curves.

– Assessed methanol compatibility by measuring tubing expansion over time.

- March 8–16: Spring break; no laboratory activities.
- March 17–21: We assembled the prototype stack, plumbing, and control electronics.

– Mounted cell, tubing, Arduino readings, and controls.

– Debugged early software crashes; stabilized serial communication.

– Executed first live fuel-cell activation with DI water.

- March 24–25: We transitioned to 3 wt% methanol feed.

– Sealed plumbing leaks and verified no backflow.

– Ran again the pump calibration at operational voltage (11.4 V, 75cc/min).

– Diagnosed and fixed zero-voltage under load: realigned MEA stack.

- March 26–28: We conducted DI water and methanol performance tests.

– Observed voltage ramp: 1 V/min to 3.3 V, then 0.1 V/min to 3.7 V unloaded.

– Monitored effluent for methanol crossover using refractive index measurements.

– Finalized dual-mode interface circuit for I–V profiling and Arduino logging.

- March 31–April 2: We recorded load tests and refined data analysis.

– Performed 20-minute loaded runs, captured I–V curves in Google Sheets.

– Consulted Dr. Osuji on interpreting polarization losses and mass-transport effects.

– Began soldering permanent control board for durability and repeatability.

- April 7–9: We optimized thermal management and code integration.

– Added auxiliary cooling fan; measured temperature impact on voltage stability.

– Adapted temperature-sensor script to plot voltage, flow rate, and temperature in real time.

– Validated logging pipeline, exporting data sets to CSV for post-processing.

- April 14: We finalized the progress log, ensuring reproducibility and transparency for future reports.

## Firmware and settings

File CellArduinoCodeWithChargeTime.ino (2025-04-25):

int pwmPin = 3; // Digital output pin connected to BJT base (via resistor)
int analogPin = A0; // Analog input pin

int timer = 0;


// Set your desired PWM parameters
float dutyCycle = 1;      
float targetFlowrate = 100;  // Set your target flowrate in cc/min
int pwmPeriodMs = 10;        // Total PWM period in milliseconds (e.g., 10ms = 100Hz)

// Define a boolean called 'feedback' and a target voltage
boolean feedback = false;  // Set to true to enable the feedback block

//set charge time
float chargeTimeDays = 40;
float m_ampsDelivered = 2000 / (chargeTimeDays*24) //assuming 2 amp hours needed finds the current output necessary
float targetCellVoltageOpen = 3.7 +  m_ampsDelivered / 13.8 ;  //Converts that current into voltage based on callibration data



void setup() {
  
  
  Serial.begin(9600);
  // Calculate duty cycle
  dutyCycle = targetFlowrate / 254.8;
  if (dutyCycle > 1.0) dutyCycle = 1.0; // Limit to 100%
  pinMode(pwmPin, OUTPUT);
  pinMode(analogPin, INPUT);
}

void loop() {
  int onTime = pwmPeriodMs * dutyCycle;
  int offTime = pwmPeriodMs - onTime;


  // Read the voltage on A0
  int sensorValue = analogRead(analogPin);
  // Convert to voltage (assuming a 5V reference) Resistor divider cuts cell output in four
  float voltage = 4 * sensorValue * (5.0 / 1023.0);

  Serial.println(voltage);


  digitalWrite(pwmPin, HIGH); // Turn BJT ON
  delay(onTime);

  digitalWrite(pwmPin, LOW);  // Turn BJT OFF
  delay(offTime);

  if (feedback) {
    if (timer % 1000 == 0) {
      // Conditional logic to adjust dutyCycle based on voltage reading
      if (voltage > targetCellVoltage + 0.1) {
        // If the voltage is greater than target by 0.1, decrease dutyCycle by 0.01
        dutyCycle -= 0.01;
      } else if (voltage < targetCellVoltage - 0.1) {
        // If the voltage is less than target by 0.1, increase dutyCycle by 0.01
        dutyCycle += 0.01;
      }
    }   
  }
  
  timer += pwmPeriodMs;

}

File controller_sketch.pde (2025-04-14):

import processing.serial.*;
import java.util.ArrayList;
import java.io.PrintWriter;

// Serial connection
Serial myPort;

// Data storage
ArrayList<Float> pvData = new ArrayList<Float>(); // Dynamic list for PV values
ArrayList<Float> svData = new ArrayList<Float>(); // Dynamic list for SV values
ArrayList<Float> pvStoredValues = new ArrayList<Float>(); // Store all PV values for CSV
ArrayList<Float> svStoredValues = new ArrayList<Float>(); // Store all SV values for CSV
ArrayList<Float> timeData = new ArrayList<Float>(); // Store all time values for CSV

// Time variables
int interval = 5; // Interval for data collection (seconds)
int counter = 0; // Counter for tracking the time

// Fixed y-axis range
float minValue = -10;
float maxValue = 50;

void setup() {
  size(600, 400);

  // Setup serial communication
  println(Serial.list()); // List all available ports
  String portName = Serial.list()[0]; // Choose the correct port from the list (adjust index as needed)
  myPort = new Serial(this, portName, 9600);
  myPort.clear(); // Clear the serial buffer at startup
  myPort.bufferUntil('\n'); // Read until newline
  
  // Initialize plot background
  background(255);
  println("Serial port connected: " + portName);
}

void draw() {
  // Only call drawPlot() after requesting and processing new data
  if (frameCount % (60 * interval) == 0) {
    requestDataFromController();
    drawPlot();
    delay(1000); // 3-second delay after plotting
  }
}

// Function to request and process data from the temperature controller
void requestDataFromController() {
  // Send the command to request Process Value (PV) and Set Value (SV)
  myPort.write(":010347000002B3\r\n"); // Same command as in the Python script
  delay(500); // Wait 1 second after sending the command

  // Wait for the response (read from the serial port)
  String response = myPort.readStringUntil('\n');
  delay(1000); // Wait an additional 1 second after receiving the response

  // Check if response is valid and process it
  if (response != null) {
    response = trim(response);
    println("Received data: " + response); // Print the raw data to verify it's being received

    try {
      // Parse the response and extract PV and SV
      //String pvHex = response.substring(0,3);
      String pvHex = response;
      
      //println(pvHex); // List all available ports
      //String svHex = response.substring(11, 15);
      // Convert from decimal to float values
      float pvValue = Float.parseFloat(pvHex);  // Parse as a decimal float
      // Convert from hexadecimal to integer and then to Centigrade
      //float pvValue = hexToCentigrade(pvHex);
      //float svValue = hexToCentigrade(svHex);
      float svValue = 4;

      // Add the process value (PV) and set value (SV) to their respective buffers
      addData(pvValue, svValue);
      
      // Save the current time
      timeData.add((float) (counter * interval)); // Time in seconds
      counter++;

      // Store values for saving later
      pvStoredValues.add(pvValue);
      svStoredValues.add(svValue);
    } catch (Exception e) {
      println("Error parsing data: " + e); // Print error for debugging
    }
  }
}

// Convert hexadecimal string to Centigrade (temperature)
float hexToCentigrade(String hexString) {
  int value = int(unhex(hexString));
  return value / 10.0;
}

// Add new data points for Process Value (PV) and Set Value (SV)
void addData(float pv, float sv) {
  pvData.add(pv);
  svData.add(sv);
  
  // Maintain a rolling window of the last 100 points for smoother plotting
  if (pvData.size() > 100) {
    pvData.remove(0); // Remove the oldest data point
    svData.remove(0); // Keep both arrays synchronized
  }

  //println("Added to plot - PV: " + pv + ", SV: " + sv); // Debugging print
}

// Draw the plot with a fixed y-axis and dynamic x-axis
void drawPlot() {
  // Clear background right before drawing the new set of data
  background(255);

  // Plot PV
  stroke(0);
  noFill();
  beginShape();
  for (int i = 0; i < pvData.size(); i++) {
    float x = map(i, 0, pvData.size() - 1, 0, width); // Dynamic x-axis based on data size
    float yPv = map(pvData.get(i), minValue, maxValue, height, 0); // Map PV to y-axis
    vertex(x, yPv);
  }
  endShape();

  // Plot SV in red
  stroke(255, 0, 0);
  beginShape();
  for (int i = 0; i < svData.size(); i++) {
    float x = map(i, 0, svData.size() - 1, 0, width);
    float ySv = map(svData.get(i), minValue, maxValue, height, 0);
    vertex(x, ySv);
  }
  endShape();

  // Add legend
  fill(0); // Set color to match PV trace
  text("PV (Process Value)", 20, 20); // Position of PV legend
  fill(255, 0, 0); // Set color to match SV trace
  text("SV (Set Value)", 20, 40); // Position of SV legend

  //println("Plotting range: minValue = " + minValue + ", maxValue = " + maxValue);
}


// Save data to a CSV file when the program is closed
void exit() {
  saveData();
  super.exit(); // Call the parent class exit method to close the sketch
}

// Save the collected data (time, PV, SV) to a CSV file
void saveData() {
  String timestamp = year() + nf(month(), 2) + nf(day(), 2) + "-" + nf(hour(), 2) + nf(minute(), 2) + nf(second(), 2);
  String fileName = sketchPath("data-" + timestamp + ".csv");

  PrintWriter output = createWriter(fileName);
  
  // Write CSV headers
  output.println("Time (s), Process Variable (PV), Set Variable (SV)");

  // Write data
  for (int i = 0; i < pvStoredValues.size(); i++) {
    output.println(timeData.get(i) + "," + pvStoredValues.get(i) + "," + svStoredValues.get(i));
  }

  output.flush();
  output.close();

  println("Data saved to " + fileName);
}

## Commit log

2025-03-05 The calibration for the peristaltic pump
    [Pump Calibration.xlsx]
2025-03-24 Add files via upload
    Arduino code for pump
2025-03-28 Mar 28 Circuit
    Photo and circuit diagram for measuring fuel cell outputs.
2025-04-11 Add files via upload
    Temperature sensor processing sketch from the fall- used as a template. Thanks to Joe for coding it.
2025-04-14 Create Edited code from temp sensor script to plot voltage
2025-04-14 Update Edited code from temp sensor script to plot voltage
2025-04-25 Create 04-25-trial-arduino
2025-04-25 Update CellArduinoCodeWithChargeTime.ino
    Updated to reflect switch to 18V power
2025-04-30 Latest code 4/30
    Includes window that goes from target charge time into a pump speed
